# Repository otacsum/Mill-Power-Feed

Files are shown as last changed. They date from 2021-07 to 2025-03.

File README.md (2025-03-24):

# Mill-Power-Feed
Arduino code, Logic Diagrams, and other assets for an X-axis Power Feed for my Milling Machine.

The v1.0.0 release is the one and only final release I will be making.  I no longer own this machine, and the power feed software seems to be in a stable state.
Any future changes to the LCD, rotary encoder, stepper drivers, or switches may need configuration or tuning.  Additionally, future updates to peripheral libraries may require updates.

User configuration parameters can be found in [`include/configuration.h`](include/configuration.h).

As stated in the [License](/docs/LICENSE) this software is provided as-is, without warranty of any kind.

### TODOs that never got done:
- Schematics
- BOM
- Embed 3rd party libraries
- Break up Classes into dedicated files

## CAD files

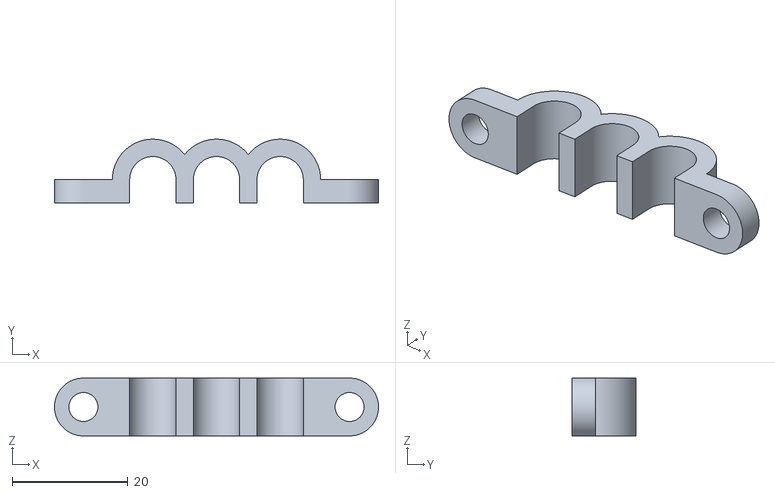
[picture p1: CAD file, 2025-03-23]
3D-Printed-Parts/DRO-Triple-Wire-Manager.stl
56.0 x 11.0 x 10.0

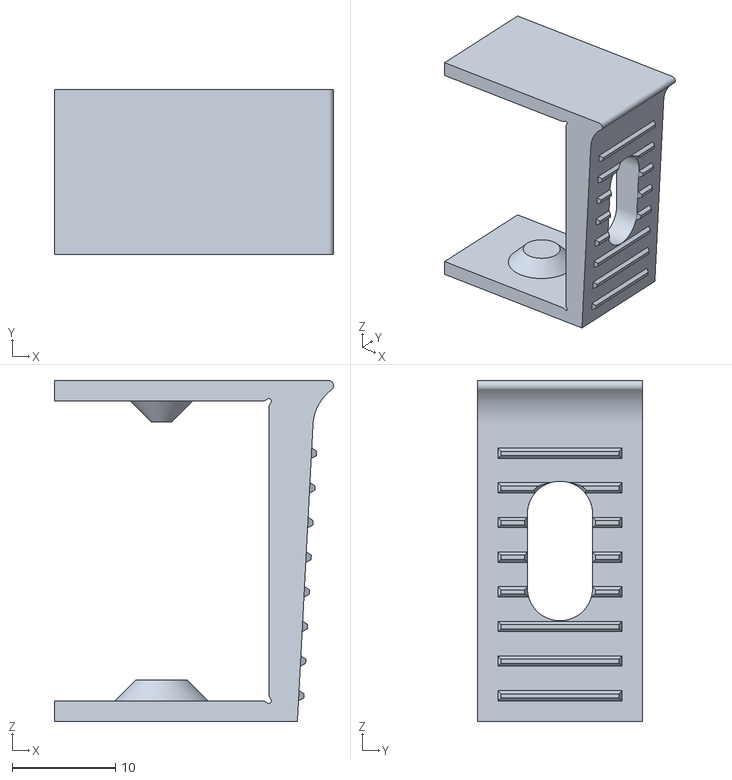
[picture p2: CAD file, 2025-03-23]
3D-Printed-Parts/DRO-Y-Scale-Mounts.stl
27.0 x 16.0 x 33.0

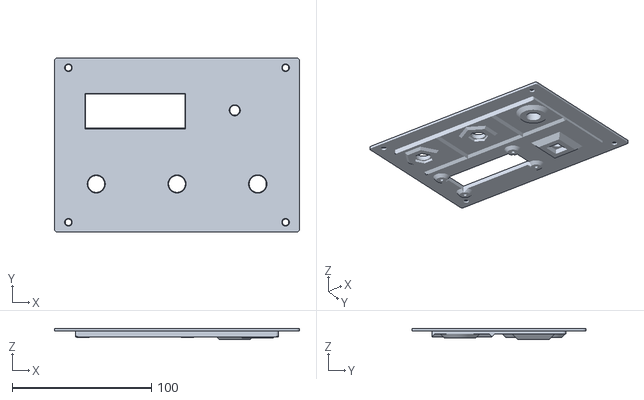
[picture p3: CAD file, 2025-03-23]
3D-Printed-Parts/Power-Feed-Switch-Plate.stl
176.0 x 125.0 x 8.00

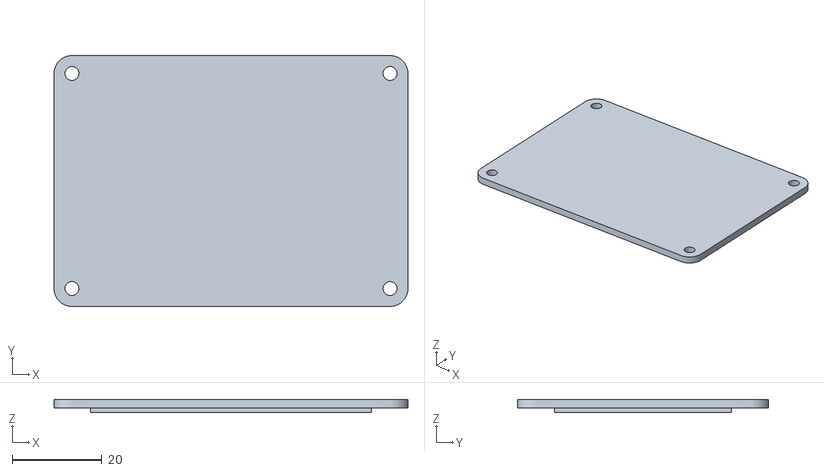
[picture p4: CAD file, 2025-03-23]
3D-Printed-Parts/Power-Feed-12v-Adapter-Lid.stl
79.0 x 56.0 x 3.00

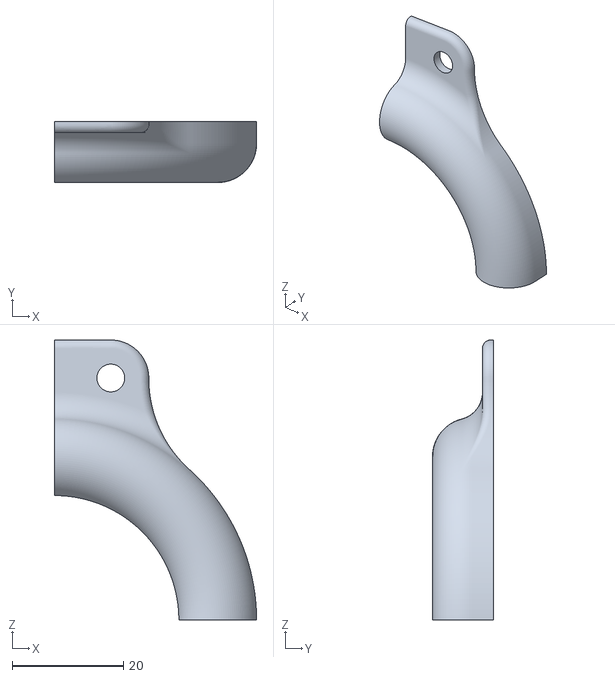
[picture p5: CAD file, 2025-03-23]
3D-Printed-Parts/DRO-Y-Wire-Manager.stl
36.4 x 11.0 x 50.4

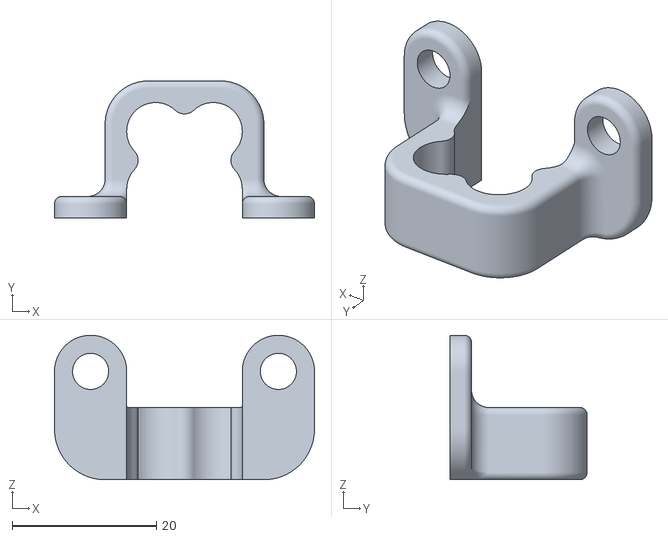
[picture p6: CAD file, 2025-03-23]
3D-Printed-Parts/DRO-Wire-Management-Stacked-Quad.stl
36.0 x 19.0 x 20.0

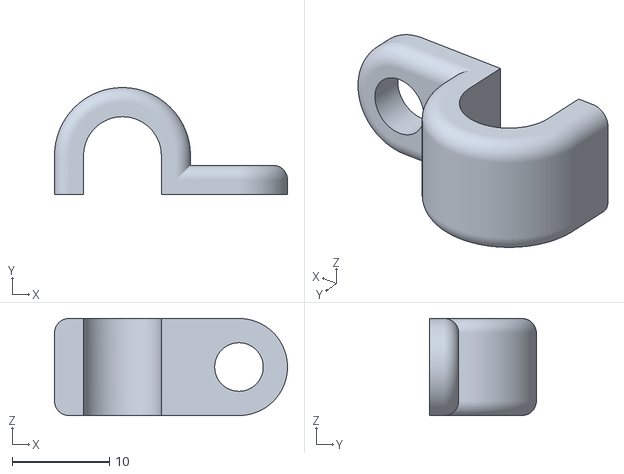
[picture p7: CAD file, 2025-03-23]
3D-Printed-Parts/DRO-Single-Wire-Manager.stl
24.0 x 11.0 x 10.0

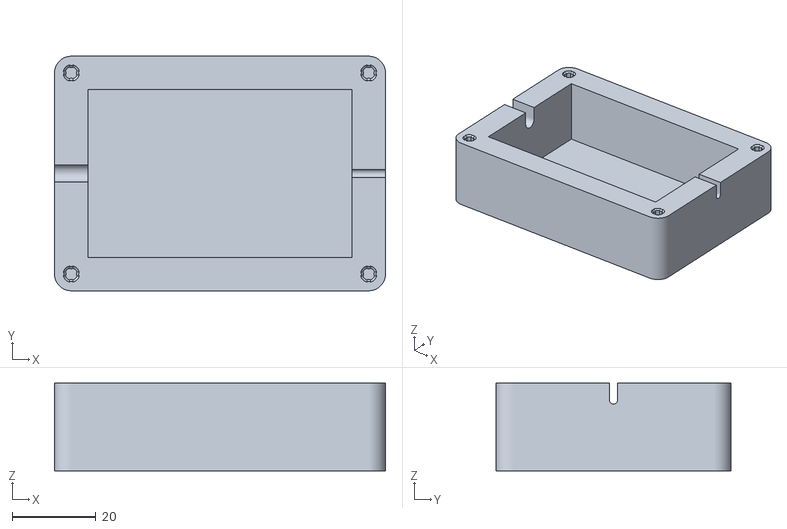
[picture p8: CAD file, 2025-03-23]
3D-Printed-Parts/Power-Feed-12v-Adapter-Box.stl
79.0 x 56.0 x 21.0

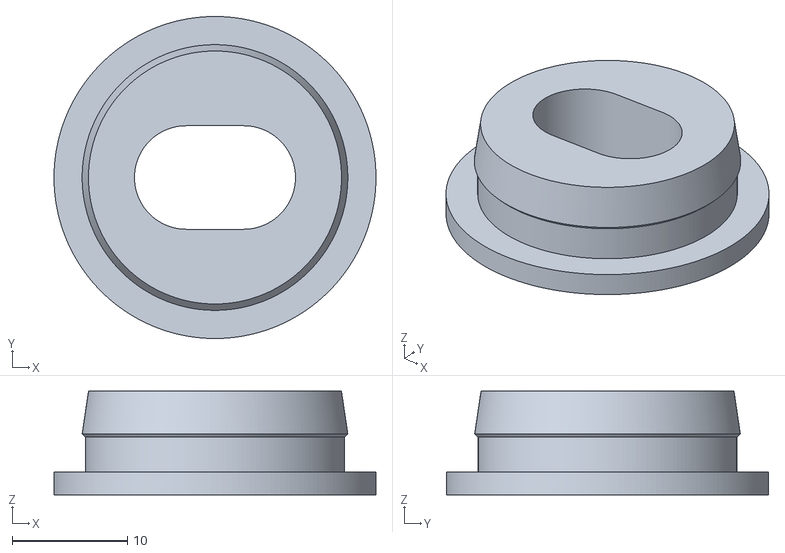
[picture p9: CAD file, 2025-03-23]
3D-Printed-Parts/Power-Feed-Cabinet-Grommet.stl
28.0 x 28.0 x 9.00

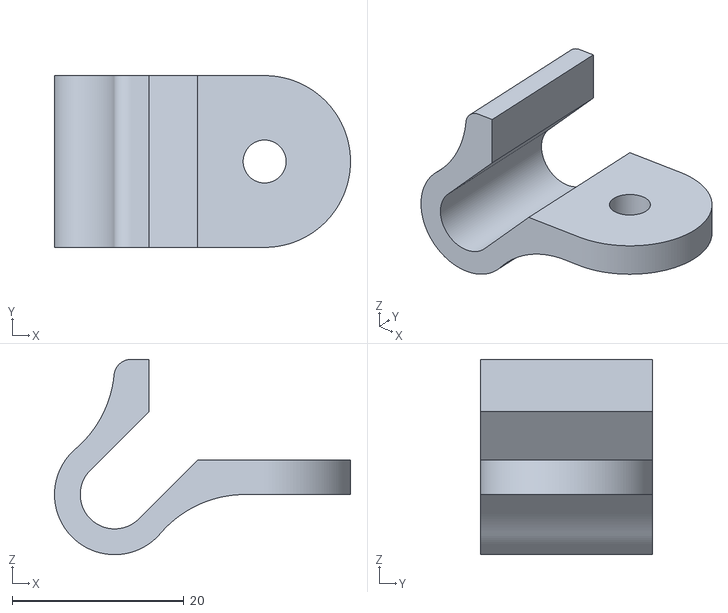
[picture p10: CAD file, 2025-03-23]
3D-Printed-Parts/DRO-X-Wire-Manager.stl
34.5 x 20.0 x 22.7

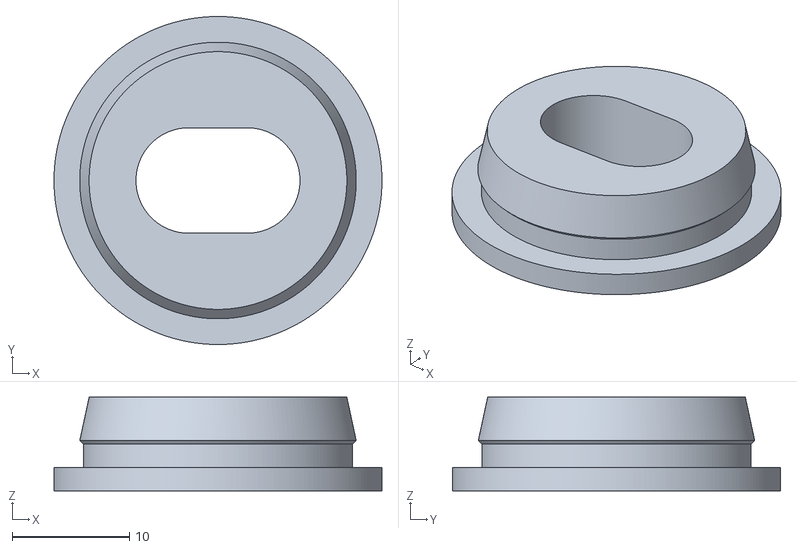
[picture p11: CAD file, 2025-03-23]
3D-Printed-Parts/Power-Feed-Control-Box-Grommet.stl
28.0 x 28.0 x 8.00

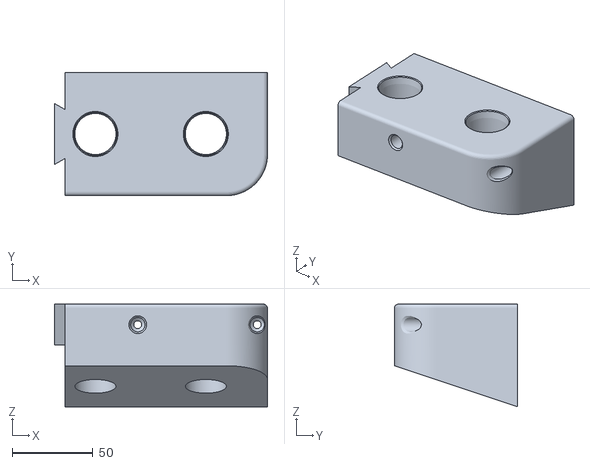
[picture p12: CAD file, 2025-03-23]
3D-Printed-Parts/R8-Collet-Rack-2-Hole.stl
131.7 x 76.2 x 63.5

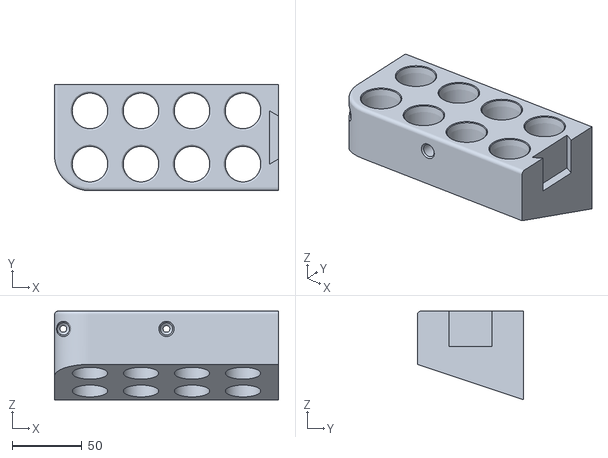
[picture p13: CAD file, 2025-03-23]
3D-Printed-Parts/R8-Collet-Rack-8-Hole.stl
160.3 x 76.2 x 63.5

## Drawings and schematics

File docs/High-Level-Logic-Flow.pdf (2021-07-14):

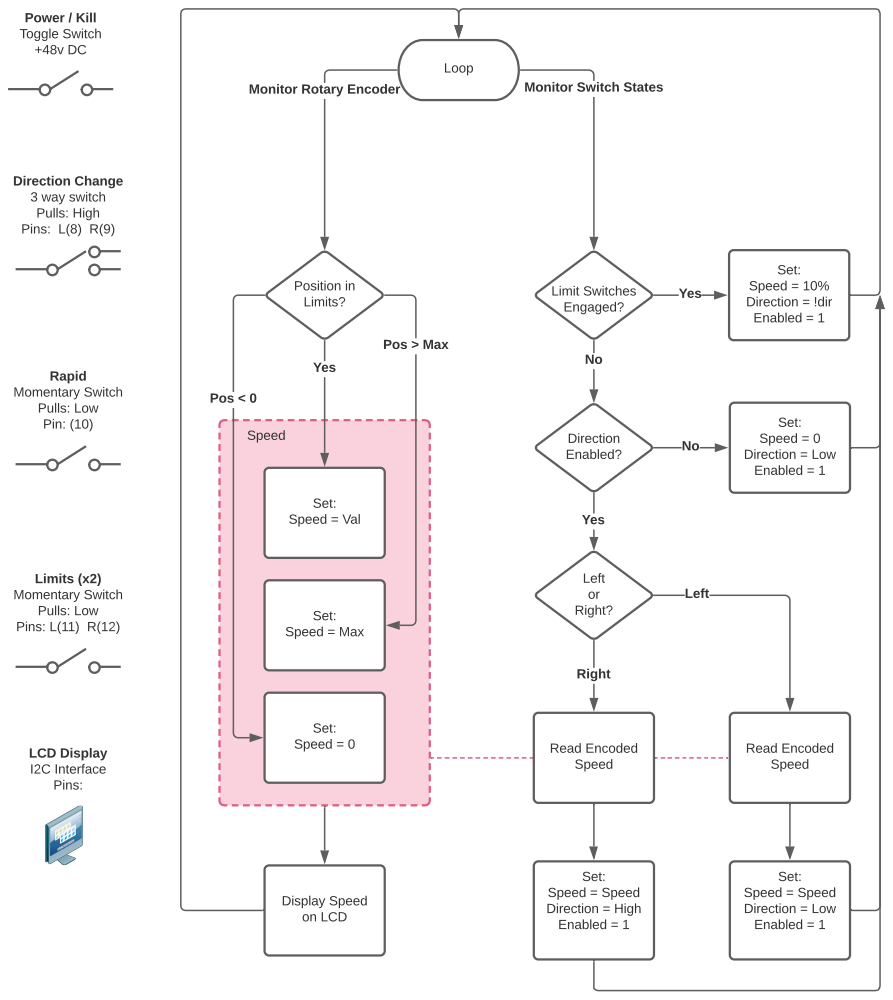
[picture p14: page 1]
Speed; Loop; Direction Enabled?; Set: Speed = 0 Direction = Low Enabled = 1; Read Encoded Speed; Monitor Rotary Encoder; Monitor Switch States; Position in Limits?; Set: Speed = Val; Yes; Set: Speed = Max; Set: Speed = 0; Pos < 0; Pos > Max; Set: Speed = Speed Direction = High Enabled = 1; Left or Right?; Right; Set: Speed = Speed Direction = Low Enabled = 1; Left; Limit Switches Engaged?; Set: Speed = 10% Direction = !dir Enabled = 1; Display Speed on LCD; Power / Kill Toggle Switch +48v DC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

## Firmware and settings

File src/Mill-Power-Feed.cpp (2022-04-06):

// Core Arduino libraries
#include <Arduino.h>
#include <FastAccelStepper.h>
#include <LiquidCrystal.h>

// Faster implementation of reading/writing pin states for fast stepper movement.
// Library uses direct port manipulation, and is nearly as fast as the obscure
// direct port manipulation syntax, but easier to read.
#include <digitalWriteFast.h> 

/* Rotary Encoder Library: http://www.pjrc.com/teensy/td_libs_Encoder.html */
#include <Encoder.h>

// Hardware and user config parameters.
#include <configuration.h>

// Create instances of #all the objects
LiquidCrystal lcd(rs_PIN, lcdEnable_PIN, d4_PIN, d5_PIN, d6_PIN, d7_PIN);
#include <LCDMessage.h> // Custom LCD events to minimize duplicate code.  
LCDMessage lcdMessage;

// Create instances of the fast stepper objects.
// Documentation at https://github.com/gin66/FastAccelStepper
FastAccelStepperEngine engine = FastAccelStepperEngine();
FastAccelStepper *stepper = NULL;

// Stepper utilities to compliment FastAccelStepper and other button states
#include <FastStepperUtils.h>
FastStepperUtils stepperUtils;

// Controller for a SPDT switch for controlling direction
#include <ThreeWaySwitch.h>
ThreeWaySwitch directionSwitch;

// Controller for a momentary SPST N/O switch for rapid function
#include <MomentarySwitch.h>
MomentarySwitch encoderButton(DEBOUNCEMILLISMOMENTARY, 1);
MomentarySwitch rapidButton(DEBOUNCEMILLISMOMENTARY, 0);


Encoder rotaryEncoder(rotaryPinA, rotaryPinB);
#include <RotaryEncoder.h> // Custom rotary encoder controller.  

void setup() {
    if (DEBUG) { // Log Events to Serial Monitor
        Serial.begin(9600);  
    }
    
    // Initializes the interface to the LCD screen, and specifies the dimensions (width and height) of the display
    lcd.begin(16,2); 

    // Initialize stepper motor stuff
    engine.init();
    stepper = engine.stepperConnectToPin(PULSE_PIN);
    if (stepper) {
        //stepper->setDirectionPin(DIRECTION_PIN);
        pinModeFast(DIRECTION_PIN, OUTPUT);
        stepper->setEnablePin(ENABLE_PIN);
        stepper->setAutoEnable(true);
        stepper->setDelayToEnable(50);
        stepper->setDelayToDisable(1000);
        stepper->setAcceleration(5000); // Steps/sec^2
        
        // Disable motors @ boot
        stepper->moveTo(1);
        stepper->stopMove();
    }

    // Initialize the pin outputs/inputs and run setup tasks
    directionSwitch.begin(threeWayPins);
    rapidButton.begin(RAPID_PIN);
    encoderButton.begin(rotaryMomentaryPin);

    // Everything is set up, let's go!
    lcdMessage.welcomeMessage();
}


void loop() { 
    directionSwitch.read();
    rapidButton.read();
    encoderButton.read();

    readRotaryEncoder(); // Abstraction to simplify encoder readings and translation to speed/events.
}

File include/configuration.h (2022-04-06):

/********  DEBUGGING  ********
 * Set truthy to turn on Serial logging for debugging.  
 * Notes:
 *  The serial log blocking time will affect RPMs &
 *  rapid changes to speed using the rotary encoder will
 *  cause the motor to halt and miss steps.
 *  Also, serial logging cannot be used to diagnose RPM inaccuracies, 
 *  you must use an external tachometer with DEBUG = false to
 *  diagnose and tune RPMs.
 */ 
bool DEBUG = false;

// Pins used for rotary encoder.  Depending on your board you 
// might need to specifically use these two pins for interrupts.  Change with caution.
// See: https://www.arduino.cc/reference/en/language/functions/external-interrupts/attachinterrupt/
#define rotaryPinA 2 // Our first hardware interrupt pin is digital pin 2
#define rotaryPinB 3 // Our second hardware interrupt pin is digital pin 3
#define rotaryMomentaryPin 5 // When pressing in on the rotary knob

// Pins used for stepper control signals
// Pulse pin must be 6, 7, or 8 by default per https://github.com/gin66/FastAccelStepper
// Other timer triplets can be used with Platform IO modifications documented ing the repo above.
#define PULSE_PIN 7 // Pin 6 doesn't work on my screw terminal board, so I used 7 instead.
#define DIRECTION_PIN 22
#define ENABLE_PIN 24

// Pins used for direction signals
#define MOVELEFT_PIN 9
#define MOVERIGHT_PIN 10

// Pin used for rapids signal
#define RAPID_PIN 11

// LCD Pins
#define rs_PIN 48
#define lcdEnable_PIN 49
#define d4_PIN 50
#define d5_PIN 51
#define d6_PIN 52
#define d7_PIN 53


//Stepper Driver Configuration Values
//#define STEPSPERREV 200 // Full-stepping (200 full steps per rev) 2x precision w/ 2:1 pulley
//#define STEPSPERREV 400 // Half-stepping (200 full steps => 400 half steps per rev) 4x precision w/ 2:1 pulley
long STEPSPERREV = 800; // Quarter-stepping (200 full steps => 800 quarter steps per rev) 8x precision w/ 2:1 pulley
int REVSPERINCH = 20; // 2:1 Pulley Reduction, 10 screw turns per inch

// Imperial milling speeds defined in IPM, to be reduced to step pulses.
// This is the maximum rate that can be programmed in using the rotary encoder and...
// also the maximum speed that will be achieved when traversing in rapid mode.
float MAXINCHESPERMIN = 36.00;
float SPEEDINCREMENT = 0.25; // Inch/Min per step of the rotary encoder.




/********* ADVANCED CONFIGURATION SETTINGS **********/

// Non-blocking delay in millis for debouncing switch state change
const unsigned long DEBOUNCEMILLISMOMENTARY = 20;
const unsigned long DEBOUNCEMILLIS3WAY = 20;

// Delay in millis for infrequent reading of switches to help motor run more efficiently.
const unsigned long SWITCHREADDELAY = 20;

// Rotary Encoder Increment Steps per Detent
// May vary per encoder, check with a test script first or adjust if
// Your increments are off by a multiple of N
int encoderStepsPerDetent = 4;






/*******************************************************************************
 *******************************************************************************
 *******************************************************************************
 * DO NOT MODIFY BELOW THIS LINE
 *******************************************************************************
 *******************************************************************************
 *******************************************************************************/
 





int PRESSED = LOW;
int UNPRESSED = HIGH;

// Velocity value set by the rotary encoder
volatile float encodedInchesPerMin = 0.00;

// Object initialization arrays
int threeWayPins[2] = {MOVELEFT_PIN, MOVERIGHT_PIN};

// Rotary encoder position at boot
long oldEncoderPosition  = -999999;

// Calculated max rotary encoder readings for Max Speed
long maxEncoderPosition = (MAXINCHESPERMIN / SPEEDINCREMENT) * encoderStepsPerDetent;

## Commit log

2021-07-14 Restructured to PlatformIO Configuration
    [configuration.h]
2021-07-14 Added non-blocking delays to switch read events, PIO framework structure, all switches OOP
    [configuration.h]
2021-07-14 README update, File structuring.
    [configuration.h]
2021-07-14 Adjustments to timer logic to help smooth acceleration
2021-07-15 Added interrupt based rotary encoder function. Buggy
    [configuration.h]
2021-07-15 Accel/Decel bugs fixed. New bug with rapid found
    [configuration.h]
2021-07-15 Mostly smooth and debugged as far as I can tell. Moving forward.
    [configuration.h]
2021-07-16 Adjustments for Mega2560 R3 compatibility, replaced rotary encoder library
    [configuration.h]
2021-07-17 Broken - stepper not pulsing
    [configuration.h]
2021-07-17 Merging writeSpeed function
    [configuration.h]
2021-07-19 Squashed acceleration bug.
    [configuration.h]
2021-07-23 Migrated ThreeWaySwitch to use FAS
    [configuration.h]
2021-07-23 Ongoing refactor to integrate with FAS lib
    [configuration.h]
2021-07-23 Mostly done, fixing pause state management
    [Mill-Power-Feed.cpp]
2021-07-26 Fixed rapid feed and direction switch bugs
    [configuration.h]
2022-04-06 Fix runaway speed bug related to direction->pause->rapid->stop->reverse direction sequence of events. Change pins for screw terminal board conveniences
    [configuration.h]
2025-03-23 Add STLs
    [DRO-Single-Wire-Manager.stl, DRO-Triple-Wire-Manager.stl, DRO-Wire-Management-Stacked-Quad.stl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]
